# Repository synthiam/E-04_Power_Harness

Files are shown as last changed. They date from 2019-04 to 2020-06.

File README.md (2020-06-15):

# E-04 Power Harness

**Project Status:** Ready to manufacture

If you are new to GitHub and would like to create a derivative of this project, please have a look at GitHub instructions to [fork a repo](https://help.github.com/en/articles/fork-a-repo)

## Description

Out of our passion to solve the issue of time waste in the robot creation process, ARC was born. The ARC software platform reduces the time it takes to get from idea to implementation. Since 2011 we have been listening to the challenges robot builders encounter and continue to provide them with an ever expanding toolbox of solutions. Join us on this journey!

We didn't stop at the software, we also made time saving hardware solutions. This power harness reference design is one of them. This harness is designed to deliver 7.4V from an RC LiPo battery (with deans connector) to the EZ-Bv4. A unique feature of this harness is that it is designed for high current applications. We want to share these files with you so you can create your own version for your community and customers to enjoy!

**Features:** 
- Replaceable fuse
- Integrated ON/OFF switch
- Deans connector input, Micro deans output
- High current rated components and wire
- Flexible silicone wire
- PCB can alternately be used with a Barrel Jack
- Voltage requirement: 0-17.5VDC (7.4V Typical)
- Current rating: 6A continuous, 20A peak
- Fuse protection: 20A ATM mini blade fuse
- Wire Length: 6"
- Dimensions: 25.9(W) x 40.9(L) x 13.9(H) (mm) PCB+fuse
- Weight: 13g

## Contents

[**Documentation:**](https://github.com/synthiam/E-04_Power_Harness/tree/master/E-04%20Documentation) BOM, Assembly Notes, Test Procedures

[**Hardware:**](https://github.com/synthiam/E-04_Power_Harness/tree/master/E-04%20Hardware) Altium PCB design File, Gerbers

*Altium Libraries are also available <a href="https://github.com/synthiam/Synthiam_Altium_Librairies">here</a>*

## Photos

<p align="left">

</p>

## Roll Out Video

This Roll-out includes:

1. Feature set 
2. Hook-up guide 
3. Bill of Materials (BOM) overview
4. Assembly instructions

Link: https://youtu.be/7Jo_VavvVQ8



## Contact

For profit use of these files requires written consent. Contact partners@synthiam.com. For everyone else, party on!

For support check out our Synthiam Community: https://synthiam.com/Community

## License

This project is released under the following license:

**Hardware:** Creative Commons Plus Attribution-NonCommercial 4.0 International (CC+ BY-NC 4.0)

Please see [LICENSE.md](https://github.com/synthiam/E-04_Power_Harness/blob/master/LICENSE.md) for license details.



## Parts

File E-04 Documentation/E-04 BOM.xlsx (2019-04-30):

Qty | Description | Manufacturer Part No. | Alternative | Designator | Custom Information | Link
E-04 Power Harness
1 | 2 layer, Blue soldermask, White silkscreen, ENIG | Micro Deans Board |  | PCB
1 | ATM Fuse holder PCB mount | BK-6011 | 3544 | ATM Fuse | Needs to be installed on top side of Micro Deans board | http://www.futureelectronics.com/en/technologies/electromechanical/circuit-protection/fuse-holders/Pages/4844270-3544.aspx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
1 | 6" of 16AWG Black Silicone Wire |  |  | Black Silicone Wire |  | https://www.alibaba.com/product-detail/300V-Black-and-Red-Soft-High_60755759788.html?s=p
1 | 6" of 16AWG Red Silicone Wire |  |  | Red Silicone Wire |  | https://www.alibaba.com/product-detail/300V-Black-and-Red-Soft-High_60755759788.html?s=p
1 | Male T plug | Y306 |  | Male Deans Ultra Plug |  | http://www.wsdeans.com/products/plugs/ultra_plug.html
1 | 6A 125VAC Mini Rocker Switch | CH865-ND |  | Mini Rocker Switch |  | https://www.digikey.ca/products/en?keywords=CH865-ND
1 | 3/16" Black Heat shrink tubing (2" length) | 3/16" Shrink Tubing |  | Heat Shrink Tubing |  | http://www.alibaba.com/product-detail/Colorized-polyolefin-heat-shrink-tubing_50608040.html?s=p
1 | Automotive fuse 20A ATM fuse | BK/ATM-20 | ATM-20 | 20A ATM fuse | Added after assembly | https://www.digikey.ca/product-detail/en/eaton-bussmann-electrical-division/BK-ATM-20/283-2330-ND/264845
1 | Micro Deans Plug | Micro Deans 2r Plug | XGW-C0418 | Micro Deans Plug | Needs to be installed beneath the Micro Deans board (soldered from top) | http://www.wsdeans.com/products/plugs/micro_plug.html

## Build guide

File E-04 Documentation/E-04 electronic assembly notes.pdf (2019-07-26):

# Electronic Assembly Notes

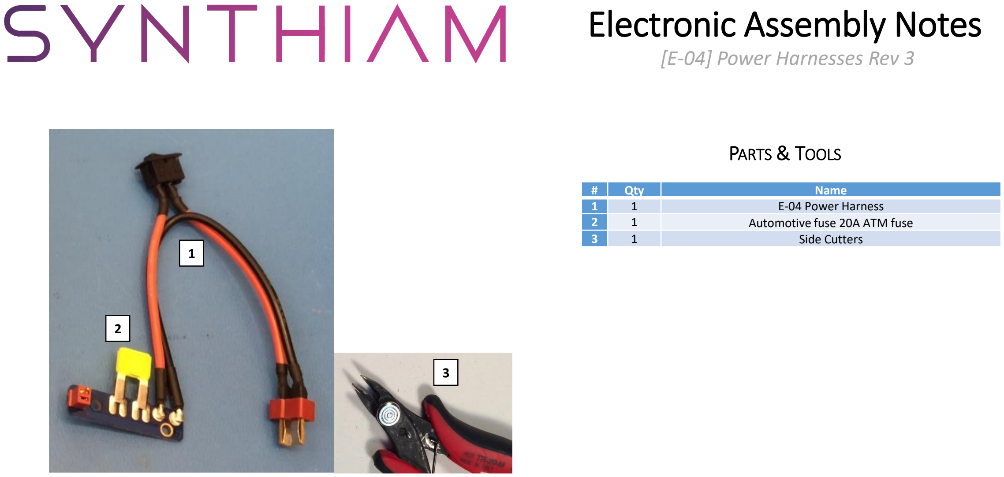
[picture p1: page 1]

[E-04] Power Harnesses Rev 3

# | Qty | Name

1 | 1 | E-04 Power Harness
2 | 1 | Automotive fuse 20A ATM fuse
3 | 1 | Side Cutters

PARTS & TOOLS

1

2

3

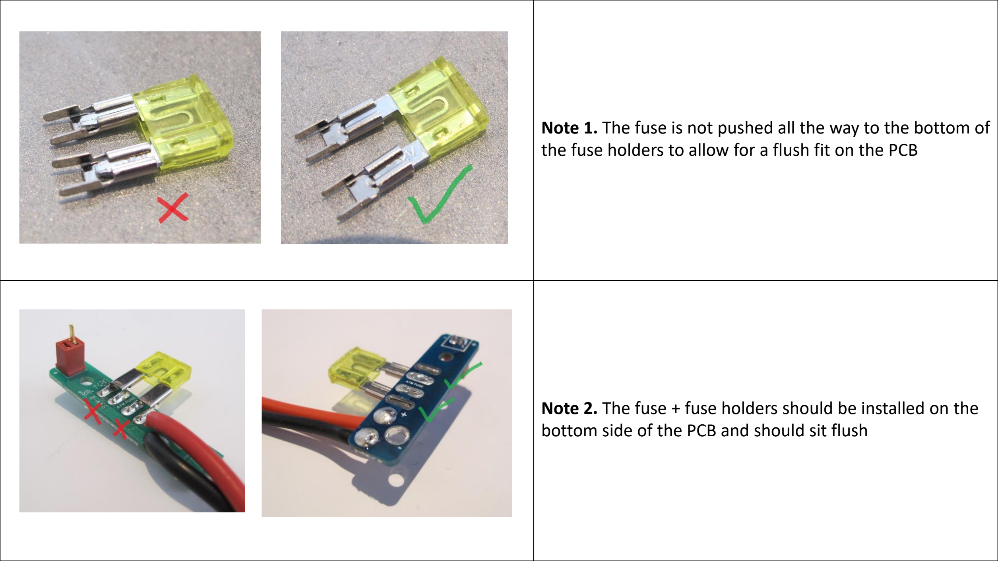
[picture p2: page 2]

Note 1. The fuse is not pushed all the way to the bottom of the fuse holders to allow for a flush fit on the PCB

Note 2. The fuse + fuse holders should be installed on the bottom side of the PCB and should sit flush

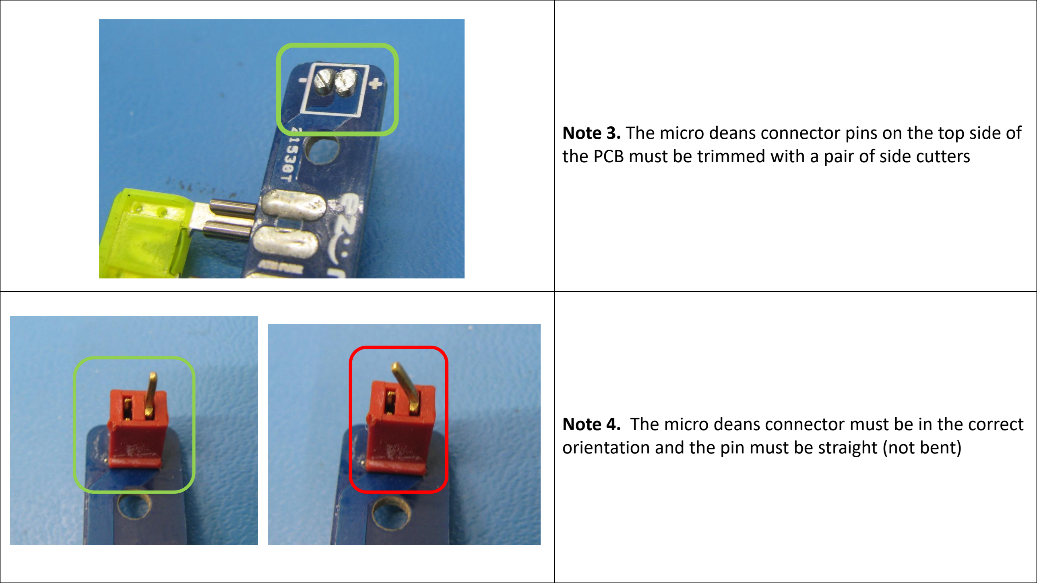
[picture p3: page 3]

Note 3. The micro deans connector pins on the top side of the PCB must be trimmed with a pair of side cutters

Note 4. The micro deans connector must be in the correct orientation and the pin must be straight (not bent)

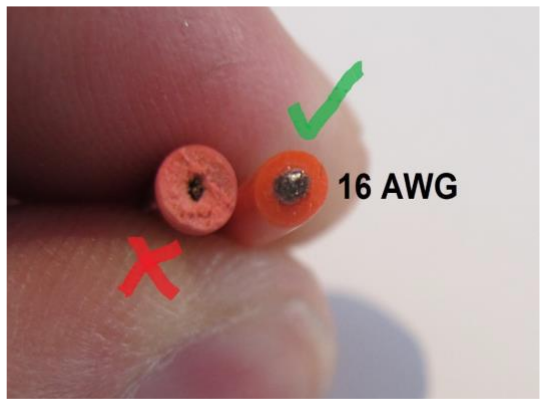
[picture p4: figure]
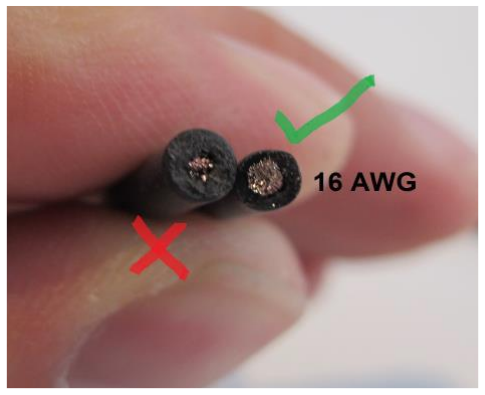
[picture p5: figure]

Note 5. The Red and Black silicone wire is 16AWG not 20AWG

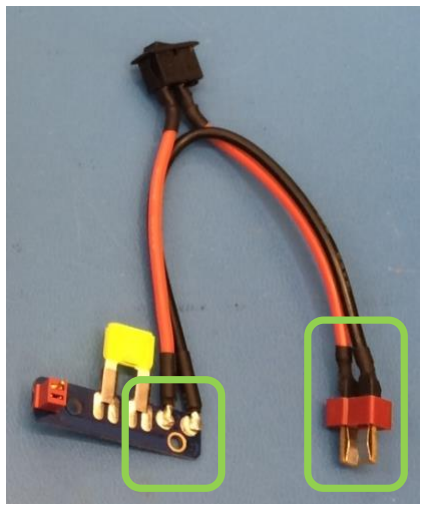
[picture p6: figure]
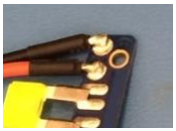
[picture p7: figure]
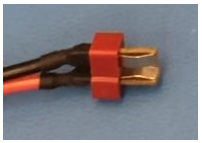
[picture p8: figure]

Note 6. Note the Red and Black wire positions on the PCB and at the Deans connector

*IMPORTANT* Correct polarity is very important!

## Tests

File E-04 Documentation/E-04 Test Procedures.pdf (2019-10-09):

# E-04 Test Procedures

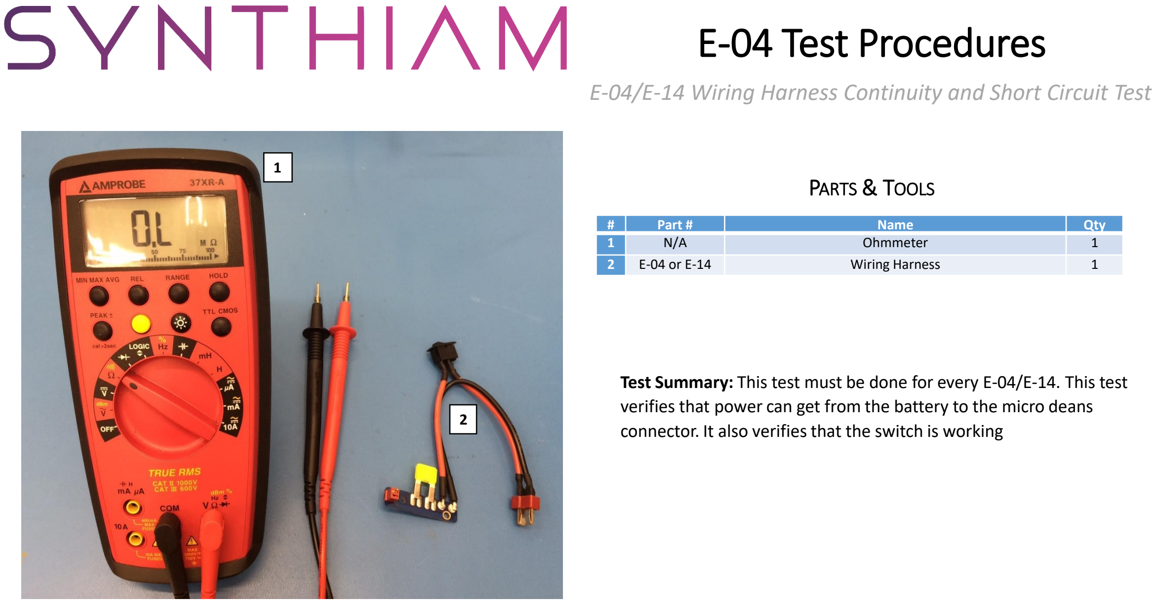
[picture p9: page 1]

# | Part # | Name | Qty

1 | N/A | Ohmmeter | 1
2 | E-04 or E-14 | Wiring Harness | 1

E-04/E-14 Wiring Harness Continuity and Short Circuit Test

PARTS & TOOLS

Test Summary: This test must be done for every E-04/E-14. This test verifies that power can get from the battery to the micro deans connector. It also verifies that the switch is working

1

2

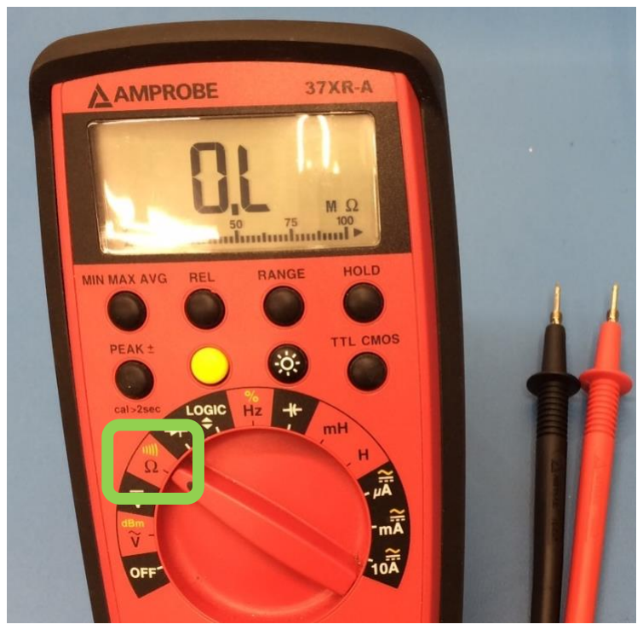
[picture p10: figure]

Step 1. Place Multimeter on the Ohms setting

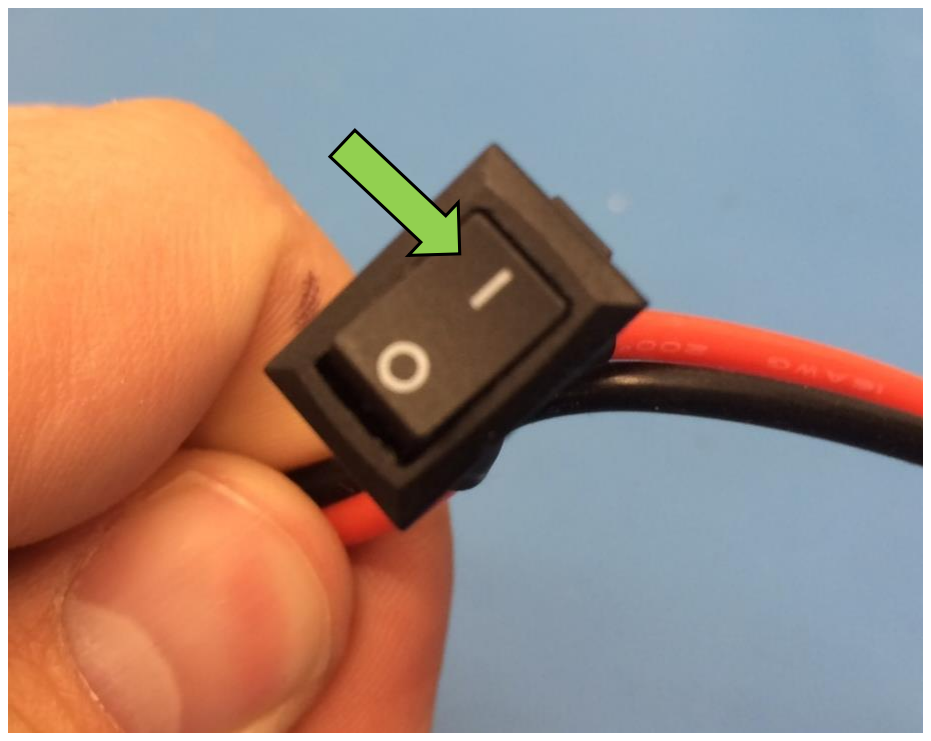
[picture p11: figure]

Step 2. Flip the switch to the ON “I” Position

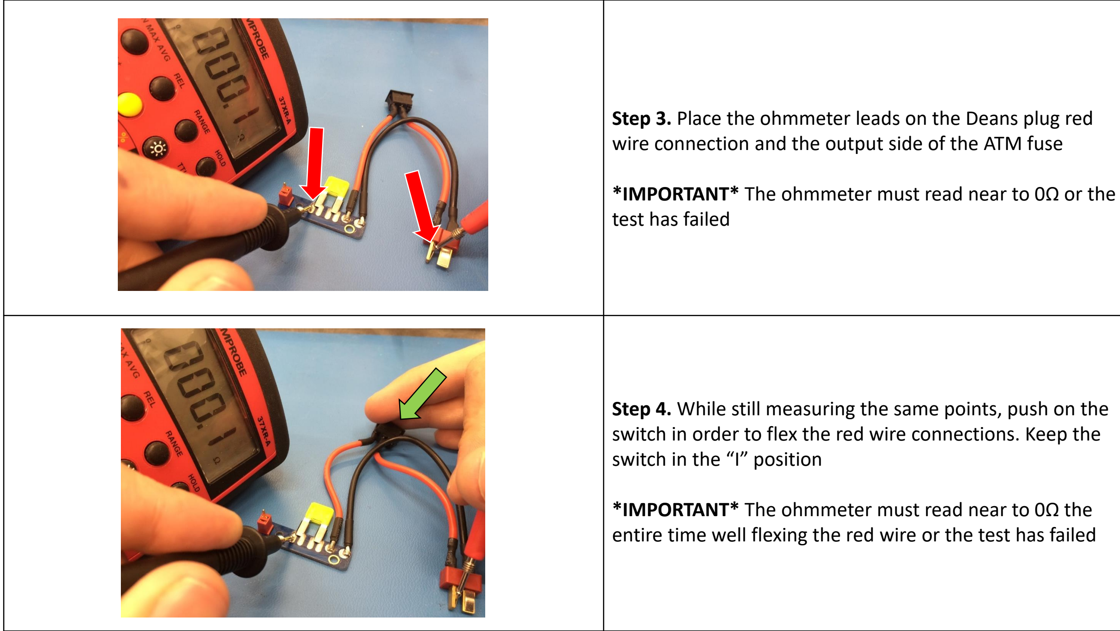
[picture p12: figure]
test has failed; switch in the “I” position

Step 3. Place the ohmmeter leads on the Deans plug red wire connection and the output side of the ATM fuse

*IMPORTANT* The ohmmeter must read near to 0Ω or the

Step 4. While still measuring the same points, push on the switch in order to flex the red wire connections. Keep the

*IMPORTANT* The ohmmeter must read near to 0Ω the entire time well flexing the red wire or the test has failed

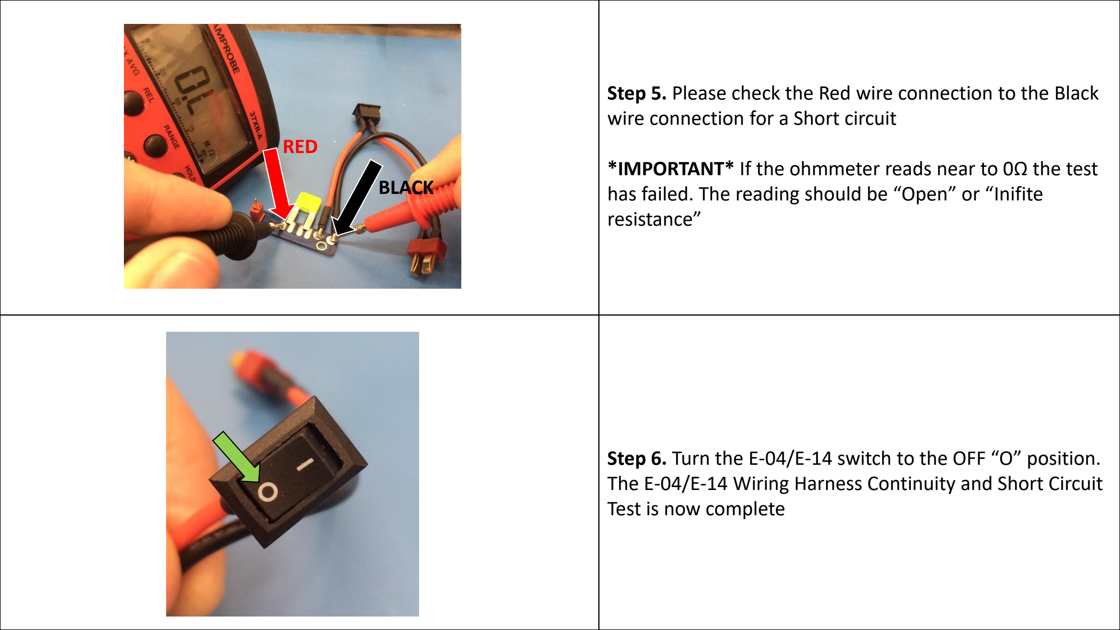
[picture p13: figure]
wire connection for a Short circuit; resistance”; Test is now complete; RED; BLACK

Step 5. Please check the Red wire connection to the Black

*IMPORTANT* If the ohmmeter reads near to 0Ω the test has failed. The reading should be “Open” or “Inifite

Step 6. Turn the E-04/E-14 switch to the OFF “O” position. The E-04/E-14 Wiring Harness Continuity and Short Circuit
